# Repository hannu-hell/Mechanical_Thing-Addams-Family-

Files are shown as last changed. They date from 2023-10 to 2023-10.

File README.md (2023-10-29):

# Mechanical_Thing-Addams-Family-
Mechanical Build of the Thing from Addams Family later featured on Netflix series Wednesday.
This project is an open source project powered by Raspberry Pi Pico W. Make sure to use the latest firmware on Pico W for Bluetooth to work.
Please follow on instructables for full build instructions.
There are two micropython files. One for the robot and one for the remote control.

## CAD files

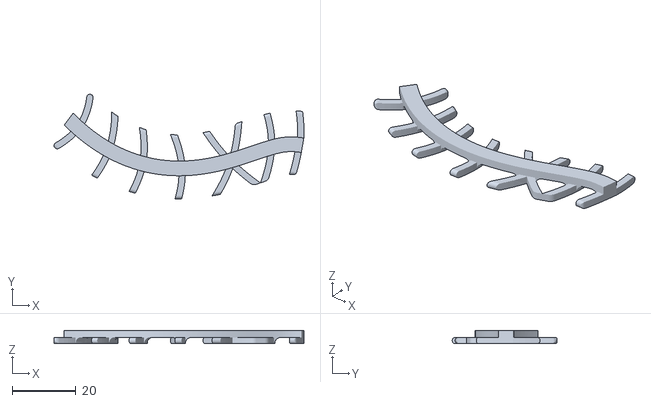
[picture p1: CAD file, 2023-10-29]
Palm_Right_Stitch.stl
78.2 x 32.7 x 4.20

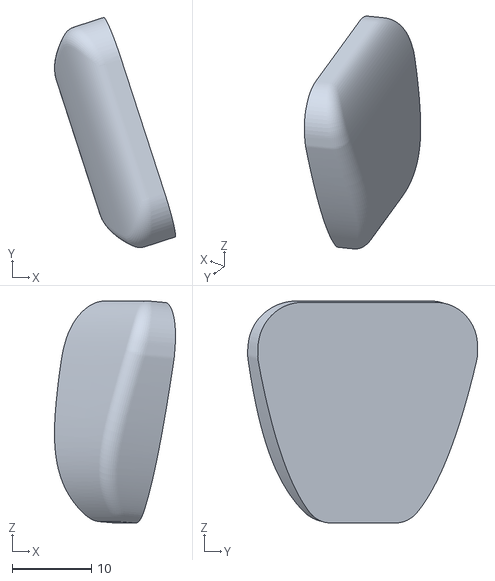
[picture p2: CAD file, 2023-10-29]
Thumb_Finger_Nail.stl
15.3 x 29.1 x 28.1

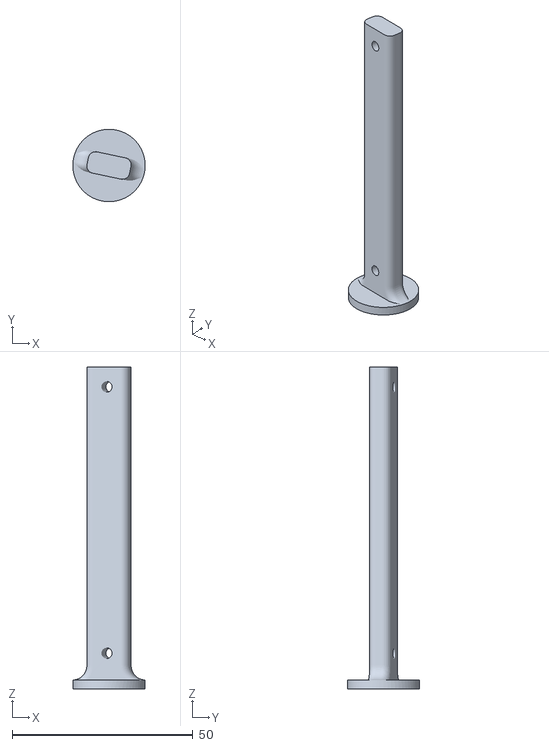
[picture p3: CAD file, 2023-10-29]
Pico_Stand.stl
20.0 x 20.0 x 89.0

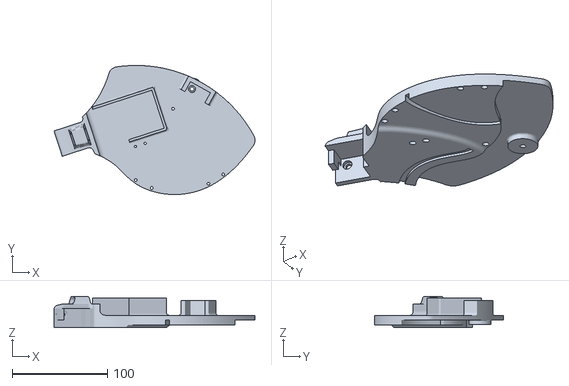
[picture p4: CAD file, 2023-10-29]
Thumb_Base.stl
211.3 x 135.7 x 33.0

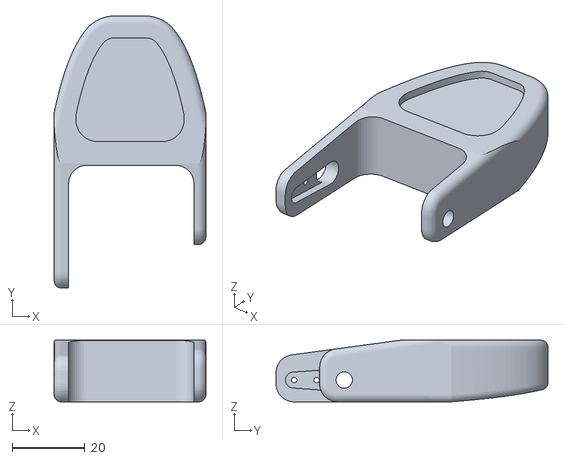
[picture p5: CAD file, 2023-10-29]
Thumb_Finger_Tip.stl
41.8 x 74.9 x 17.0

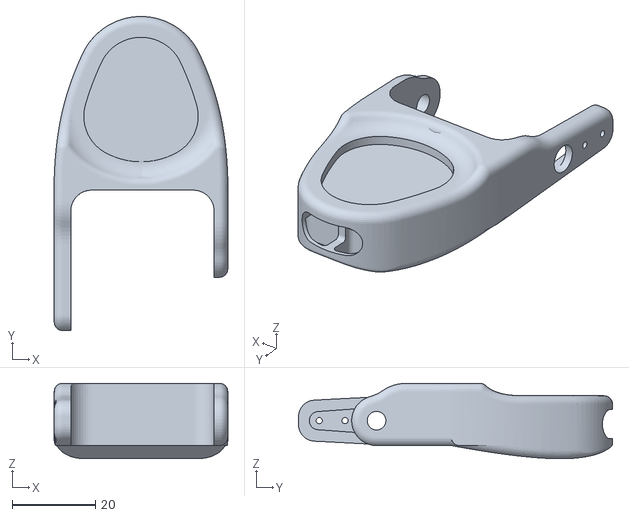
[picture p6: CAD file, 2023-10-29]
Finger_Tip.stl
41.8 x 75.6 x 18.2

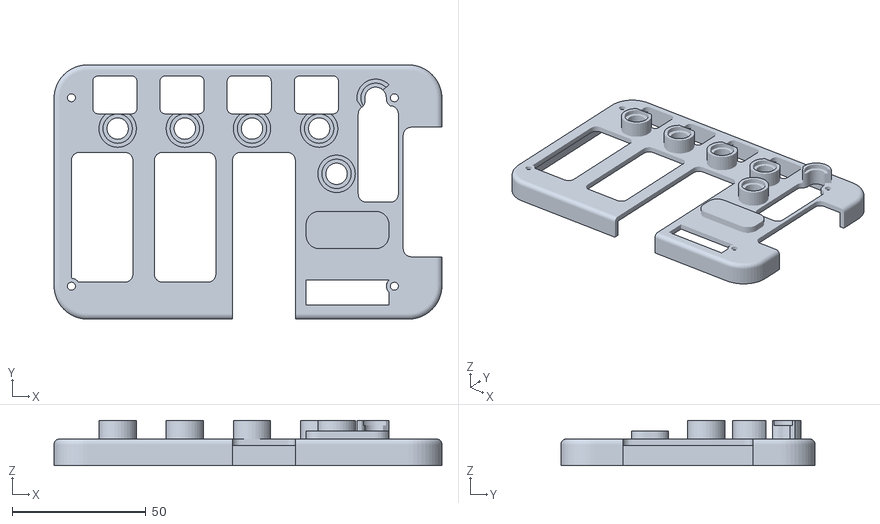
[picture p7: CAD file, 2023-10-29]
Remote_Top_Case.stl
145.0 x 95.0 x 17.0

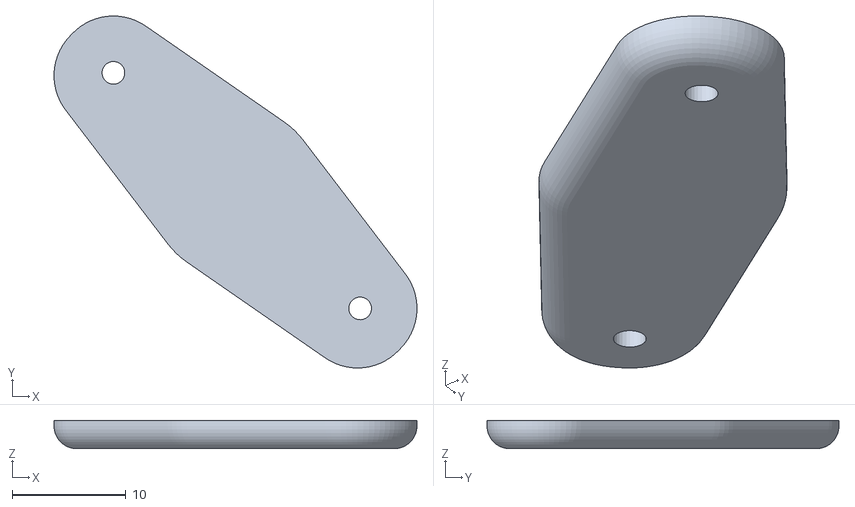
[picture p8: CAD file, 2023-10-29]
Base_Servo_Cap.stl
31.9 x 31.0 x 2.50

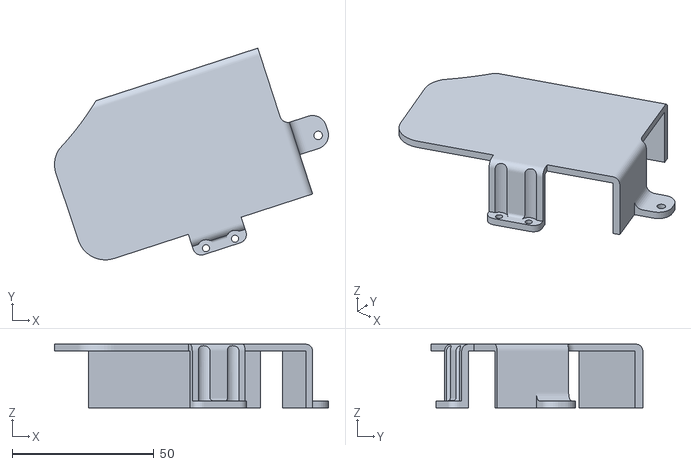
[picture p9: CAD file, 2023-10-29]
Battery_Panel.stl
96.8 x 74.8 x 22.5

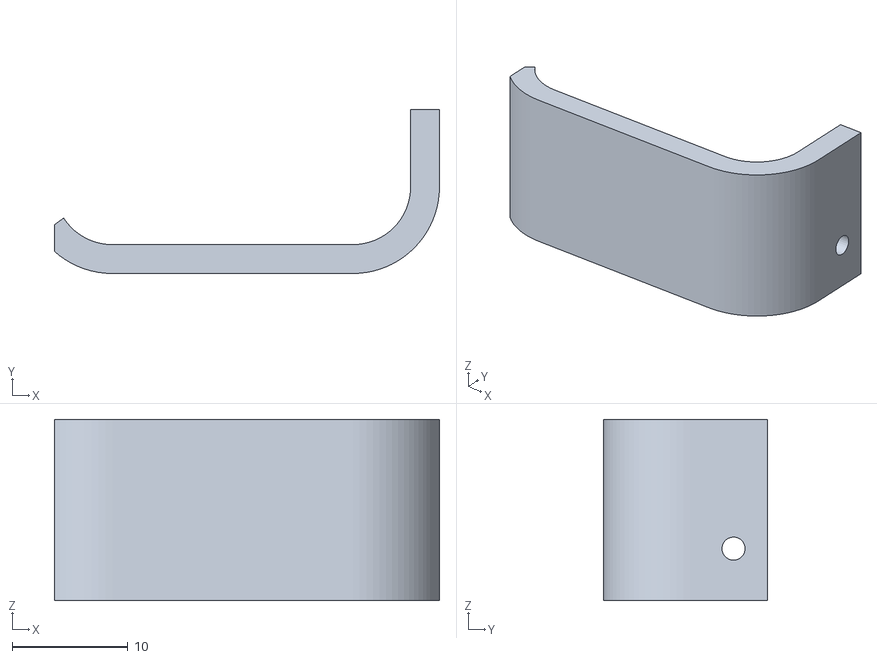
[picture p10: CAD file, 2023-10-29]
Buck_Convertor_Cover.stl
33.3 x 14.2 x 15.7

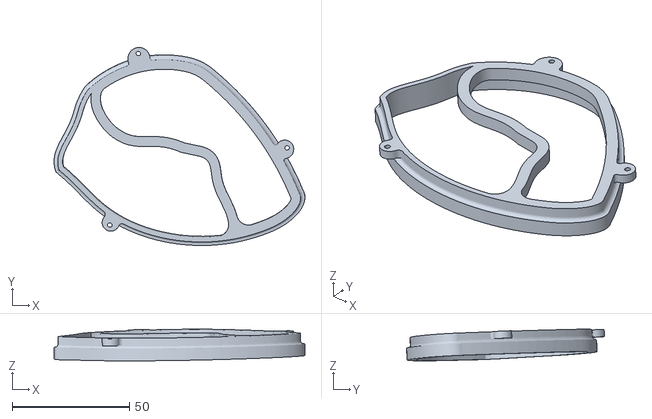
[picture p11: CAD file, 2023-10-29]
Wrist_Top_Cap.stl
106.8 x 84.3 x 13.5

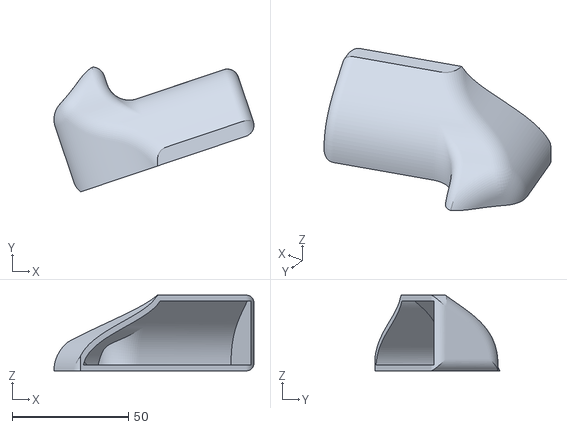
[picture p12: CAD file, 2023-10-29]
Hand_Panel.stl
85.9 x 53.6 x 32.5

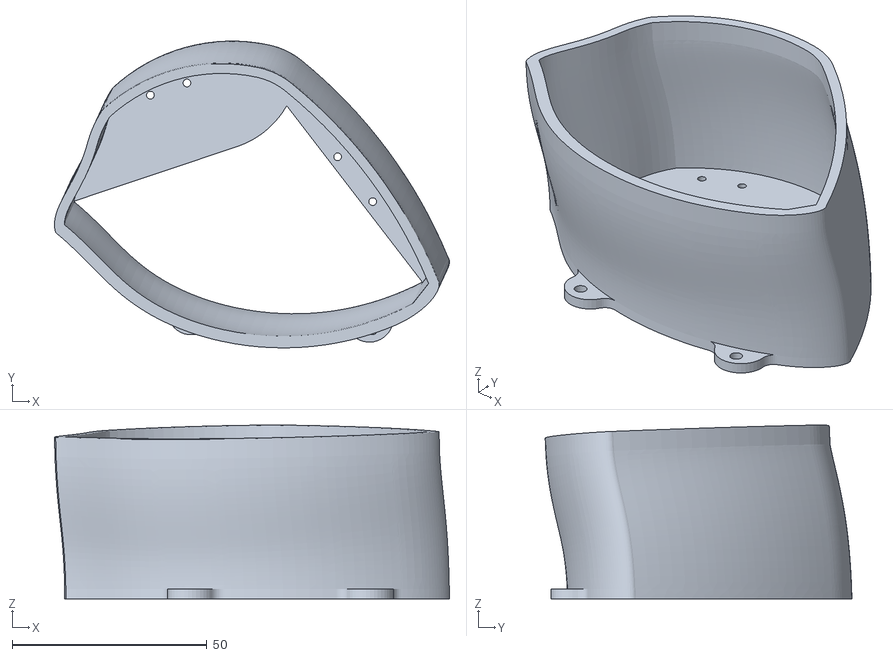
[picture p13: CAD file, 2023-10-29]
Wrist_Top.stl
101.4 x 78.7 x 44.6

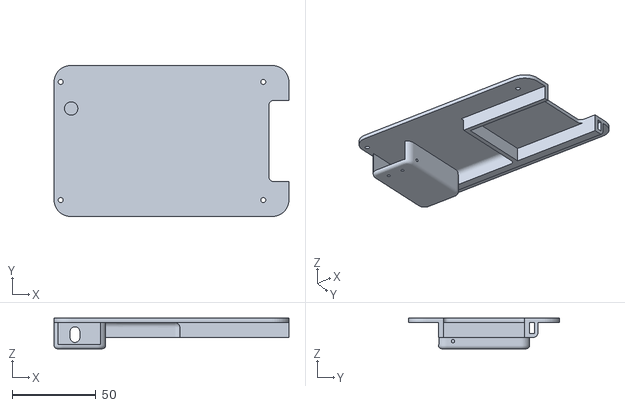
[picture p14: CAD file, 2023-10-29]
Remote_Base.stl
140.0 x 90.0 x 18.2

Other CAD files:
Index_Finger_Mid.stl
Hand_Front.stl
Finger_Nail.stl
Fingers_Horn.stl
Cracked_Finger_Nail.stl
Index_Finger_Base.stl
Wrist.stl

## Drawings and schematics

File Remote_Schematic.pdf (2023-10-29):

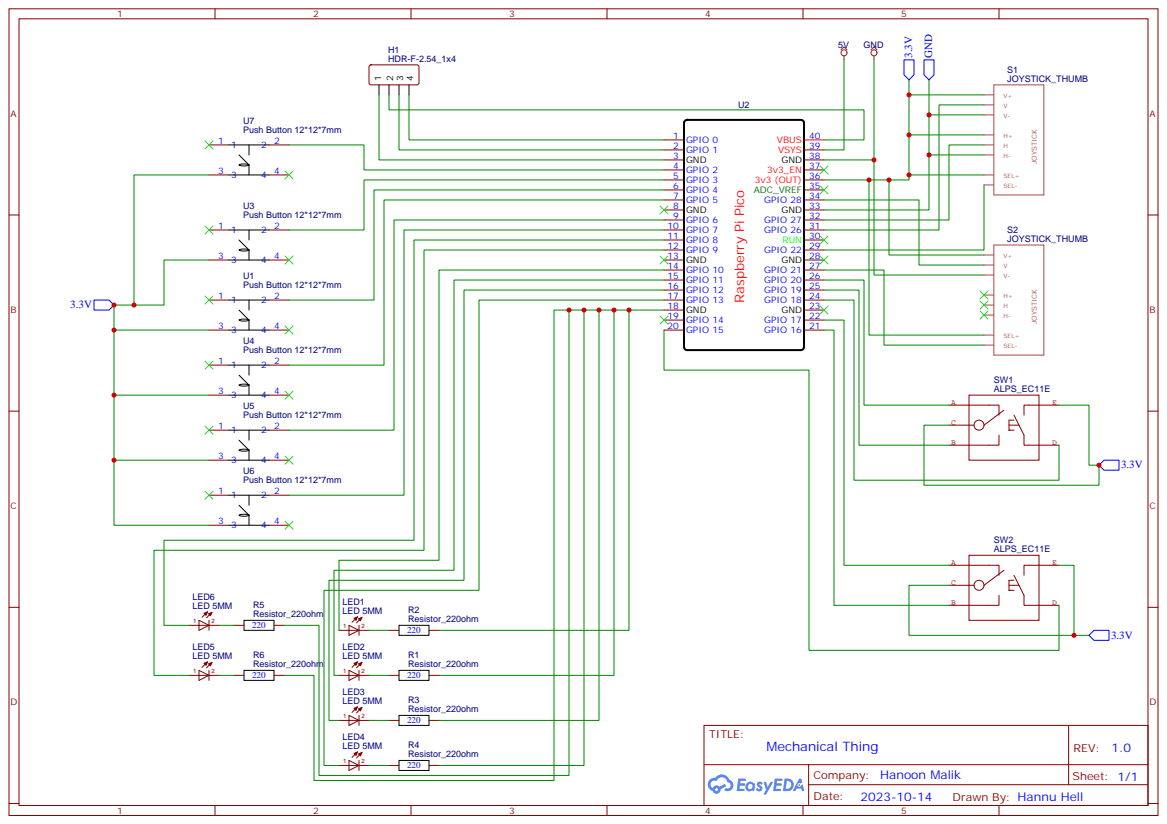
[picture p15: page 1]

Drawn By: Hannu Hell

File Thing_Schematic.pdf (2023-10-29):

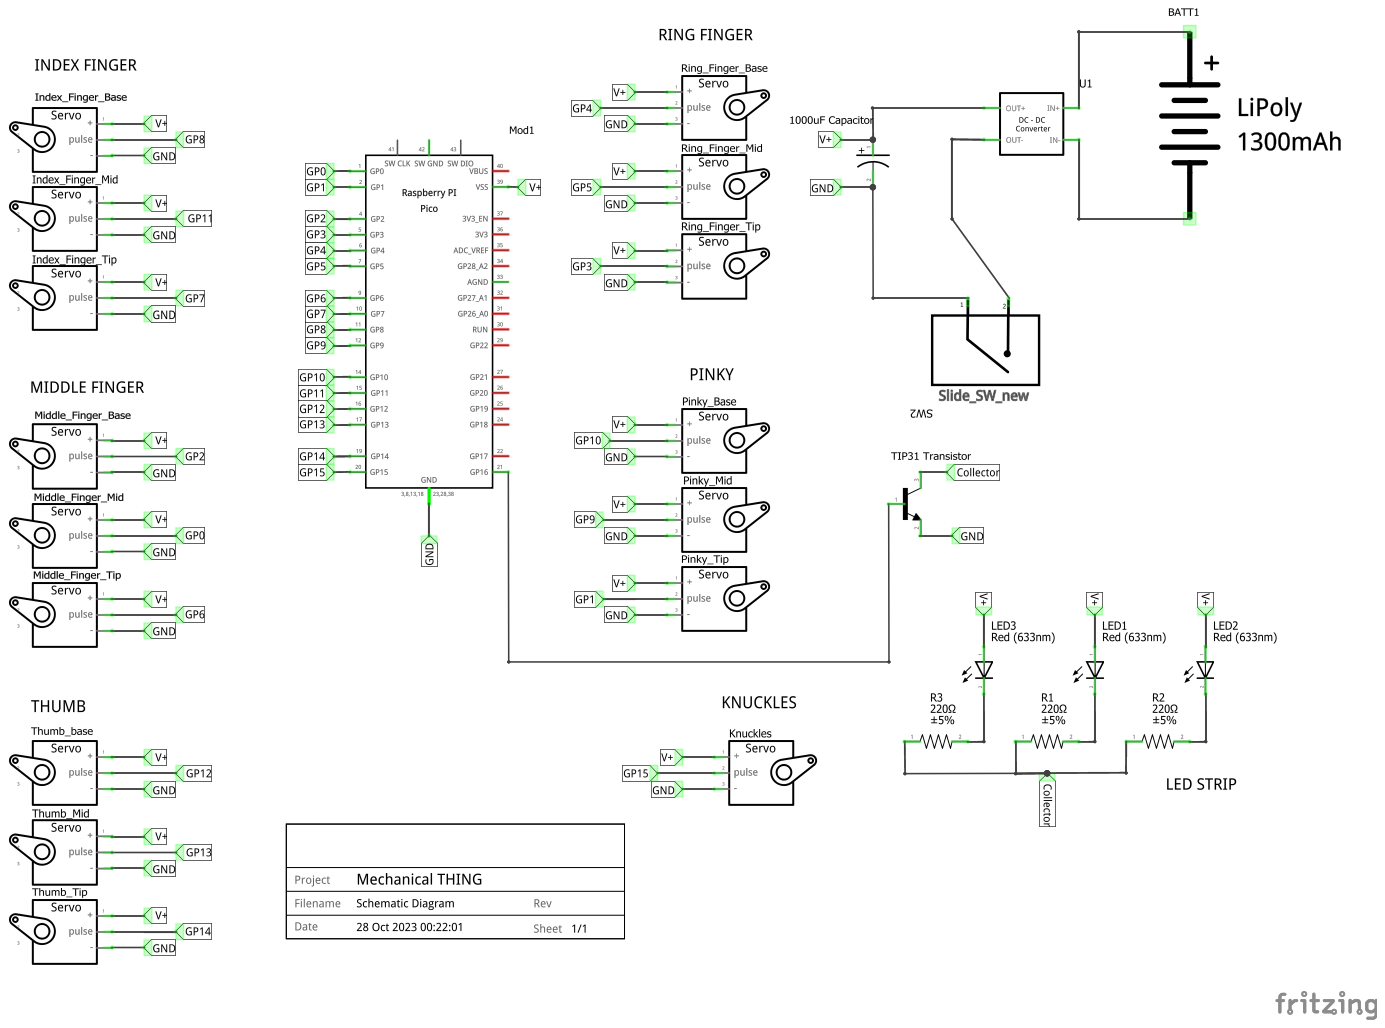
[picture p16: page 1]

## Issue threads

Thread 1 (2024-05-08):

Can you provide the full 3d design file?

pepijndik, 2024-05-08:
First of all what an awesome project!
For school, we are working on exactly the same and thought let's use your instructables as an example ;-) Now we are facing a small issue. We wanted to reuse your design and alter it a bit. But because those are STL files we can't modify them.  en because converting them into a mesh didn't work. so  I thought maybe you could share the cad files instead of the. stl files

Kind regards!

hannu-hell, 2024-05-09:
Hi pepjin,

Glad that you liked my project and its of use to your studies. I’ll figure out a way to embed the design in the instructable so that u will be able to open it in fusion360.

Sorry for the late reply.
Kind regards,
Hannu
Sent from my iPhone

On 08-05-2024, at 21:59, pepijn ***@***.***> wrote:

First of all what an awesome project!
For school, we are working on exactly the same and thought let's use your instructables as an example ;-) Now we are facing a small issue. We wanted to reuse your design and alter it a bit. But because those are STL files we can't modify them. en because converting them into a mesh didn't work. so I thought maybe you could share the cad files instead of the. stl files

Kind regards!

—
Reply to this email directly, view it on GitHub<https://github.com/hannu-hell/Mechanical_Thing-Addams-Family-/issues/1>, or unsubscribe<https://github.com/notifications/unsubscribe-auth/AJKEGCPOTOZHCNZXDDYAFNDZBIVUZAVCNFSM6AAAAABHNBB45WVHI2DSMVQWIX3LMV43ASLTON2WKOZSGI4DKNRXG44TMOA>.
You are receiving this because you are subscribed to this thread.Message ID: ***@***.***>

pepijndik, 2024-05-09:
Thx would be nice, if you only could share them through github also fine😃.

Kind regards

hannu-hell, 2024-05-14:
Hi Pepjin,
I am unable to share the fusion360 file here since its not supported here. Provide me your email and Ill be able to attach the file and send it to you.

Kind Regards

hannu-hell, 2024-05-14:
Oh nevermind,
I've uploaded the file to the repository. Hope it helps.

Closed 2024-06-13.

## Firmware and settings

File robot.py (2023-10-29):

from machine import Pin
import time
from servo import Servo

import aioble
import bluetooth
import machine
import uasyncio as asyncio

# Bluetooth UUIDS can be found online at https://www.bluetooth.com/specifications/gatt/services/
_REMOTE_UUID = bluetooth.UUID(0x1848)
_ENV_SENSE_UUID = bluetooth.UUID(0x1800) 
_REMOTE_CHARACTERISTICS_UUID = bluetooth.UUID(0x2A6E)

# Pico onboard LED for bluetooth connectivity indication
led = machine.Pin("LED", machine.Pin.OUT)
connected = False
alive = False

wrist_led = Pin(16, Pin.OUT)
wrist_led.value(0)

# Finger Servo Pin Definitions
ib = 8
im = 11
it = 7

mb = 2
mm = 0
mt = 6

rb = 4
rm = 5
rt = 3

pb = 10
pm = 9
pt = 1

tb = 12
tm = 13
tt = 14

# Knuckles servo Pin definition
w = 15

# Create servo objects for all the joints
# Index Finger
i_b = Servo(pin_id=ib)
i_m = Servo(pin_id=im)
i_t = Servo(pin_id=it)
# Middle Finger
m_b = Servo(pin_id=mb)
m_m = Servo(pin_id=mm)
m_t = Servo(pin_id=mt)
# Ring FInger
r_b = Servo(pin_id=rb)
r_m = Servo(pin_id=rm)
r_t = Servo(pin_id=rt)
# Pinky 
p_b = Servo(pin_id=pb)
p_m = Servo(pin_id=pm)
p_t = Servo(pin_id=pt)
# Thumb
t_b = Servo(pin_id=tb)
t_m = Servo(pin_id=tm)
t_t = Servo(pin_id=tt)
# Knuckles
wrt = Servo(pin_id=w)

delay_ms = 20


async def find_remote():
    # Scan for 5 seconds, in active mode, with very low interval/window (to
    # maximise detection rate).
    async with aioble.scan(5000, interval_us=30000, window_us=30000, active=True) as scanner:
        async for result in scanner:

            # See if it matches our name
            if result.name() == "TheThing":
                print("Found The_Thing")
                for item in result.services():
                    print (item)
                if _ENV_SENSE_UUID in result.services():
                    print("Found Robot Remote Service")
                    return result.device
            
    return None

async def blink_task():
    """ Blink the LED on and off every second """
    
    toggle = True
    
    while True and alive:
        led.value(toggle)
        toggle = not toggle
        # print(f'blink {toggle}, connected: {connected}')
        if connected:
            blink = 1000
        else:
            blink = 250
        await asyncio.sleep_ms(blink)

async def peripheral_task():
    print('starting peripheral task')
    global connected
    connected = False
    device = await find_remote()
    if not device:
        print("Robot Remote not found")
        return
    try:
        print("Connecting to", device)
        connection = await device.connect()
        
    except asyncio.TimeoutError:
        print("Timeout during connection")
        return
      
    async with connection:
        print("Connected")
        connected = True
        alive = True
        while True and alive:
            try:
                robot_service = await connection.service(_REMOTE_UUID)
                print(robot_service)
                control_characteristic = await robot_service.characteristic(_REMOTE_CHARACTERISTICS_UUID)
                print(control_characteristic)
            except asyncio.TimeoutError:
                print("Timeout discovering services/characteristics")
                return
            while True:
                if control_characteristic != None:
                    try:
                        command = await control_characteristic.read()
                        if command == b'r':
                            print("a button pressed")
                            crouch_pos()
                        if command == b'b':
                            print("b button pressed")
                            get_up()
                        if command == b'g':
                            print("x button pressed")
                            finger_stamp()
                        if command == b'y':
                            print("y button pressed")
                            point_finger()
                        if command == b'w':
                            print("y button pressed")
                            bow_down()
                        if command == b'k':
                            print("y button pressed")
                            rise_up()
                        if command == b'x':
                            print("y button pressed")
                            crouch_walk_forward()
                        if command == b'z':
                            print("y button pressed")
                            crouch_walk_backward()
                        if command == b'v':
                            print("y button pressed")
                            stand_walk()
                    except TypeError:
                        print(f'something went wrong; remote disconnected?')
                        connected = False
                        alive = False
                        return
                    except asyncio.TimeoutError:
                        print(f'something went wrong; timeout error?')
                        connected = False
                        alive = False
                        return
                    except asyncio.GattError:
                        print(f'something went wrong; Gatt error - did the remote die?')
                        connected = False
                        alive = False
                        return
                else:
                    print('no characteristic')
                await asyncio.sleep_ms(10)

async def main():
    tasks = []
    tasks = [
        asyncio.create_task(blink_task()),
        asyncio.create_task(peripheral_task()),
    ]
    await asyncio.gather(*tasks)

def wrist_led_seq():
    wrist_led.value(0)
    time.sleep(2)
    wrist_led.value(0)
    for i in range (3):
        wrist_led.value(1)
        time.sleep(0.1)
        wrist_led.value(0)
        time.sleep(0.1)
    wrist_led.value(1)

def straight_fingers():
    i_b.write(76)
    i_m.write(15)
    i_t.write(55)

    m_b.write(87)
    m_m.write(44)
    m_t.write(58)

    r_b.write(85)
    r_m.write(35)
    r_t.write(60)

    p_b.write(88)
    p_m.write(45)
    p_t.write(45)
    
    t_b.write(88)
    t_m.write(48)
    t_t.write(78)
    
    time.sleep(1)
   
def rise_up():
    straight_fingers()
    time.sleep(2)

    t_b.write(84)
    t_m.write(80)
    t_t.write(170)
    time.sleep(2)

    t_b.write(84-50)
    t_m.write(48+100)
    time.sleep(1)
    t_b.write(88-50)
    t_m.write(48+70)
    t_t.write(78+52)
    time.sleep(1)

    t_b.write(88-60)
    t_m.write(48+90)
    t_t.write(78+52)

    time.sleep(0.5)

    i_b.write(76-20)
    i_m.write(15)
    i_t.write(55)
    time.sleep(1)
    m_b.write(87-20)
    m_m.write(44)
    m_t.write(58)

    r_b.write(85-20)
    r_m.write(35)
    r_t.write(60)

    p_b.write(88-20)
    p_m.write(45)
    p_t.write(45)

    time.sleep(1)

    t_b.write(88-4)
    t_m.write(48+125)
    t_t.write(78-32)
    time.sleep(1)
    p_b.write(88-27)
    p_m.write(45+30)
    p_t.write(45+87)
    time.sleep(1)
    i_b.write(76-27)
    i_m.write(15+30)
    i_t.write(55+87)

    m_b.write(87-27)
    m_m.write(44+30)
    m_t.write(58+87)

    r_b.write(85-27)
    r_m.write(35+30)
    r_t.write(60+87)

    time.sleep(1)
    p_b.write(88-12)
    p_m.write(45+104)
    p_t.write(45-2)

    t_b.write(88-4)
    t_m.write(48+125)
    t_t.write(78-32)

    time.sleep(1)
    r_b.write(85-12)
    r_m.write(35+104)
    r_t.write(60-2)
    time.sleep(1)
    m_b.write(87-12)
    m_m.write(44+104)
    m_t.write(58-2)
    time.sleep(1)
    i_b.write(76-12)
    i_m.write(15+104)
    i_t.write(55-2)

    time.sleep(1)

    crouch_pos()
    time.sleep(1)
    crouch_walk_backward(steps=1)

    time.sleep(1)
    t_b.write(88-6)
    t_m.write(48+145)
    t_t.write(78-10)
    time.sleep(1)
    get_up()

def finger_stamp():
    for i in range(10):
        i_b.write(76-4)
        i_m.write(15+125)
        i_t.write(55-32)
        time.sleep(0.1)
        i_b.write(76-63)
        i_m.write(15+138)
        i_t.write(55+15)
        time.sleep(0.1)
        i_b.write(76-12)
        i_m.write(15+104)
        i_t.write(55-2)

        m_b.write(87-4)
        m_m.write(44+125)
        m_t.write(58-32)
        time.sleep(0.1)
        m_b.write(87-63)
        m_m.write(44+138)
        m_t.write(58+15)
        time.sleep(0.1)
        m_b.write(87-12)
        m_m.write(44+104)
        m_t.write(58-2)

        r_b.write(85-4)
        r_m.write(35+125)
        r_t.write(60-32)

        p_b.write(88-4)
        p_m.write(45+125)
        p_t.write(45-32)

        t_b.write(88-4)
        t_m.write(48+125)
        t_t.write(78-32)

def get_up():
    i_b.write(76-4)
    i_m.write(15+125)
    i_t.write(55-32)
    
    m_b.write(87-4)
    m_m.write(44+125)
    m_t.write(58-32)

    r_b.write(85-4)
    r_m.write(35+125)
    r_t.write(60-32)

    p_b.write(88-4)
    p_m.write(45+125)
    p_t.write(45-32)

    t_b.write(88-4)
    t_m.write(48+125)
    t_t.write(78-32)
    
    time.sleep(2)
    
    m_b.write(87+59)
    m_m.write(44+60)
    m_t.write(58-29)

    r_b.write(85+59)
    r_m.write(35+60)
    r_t.write(60-29)

    p_b.write(88+59)
    p_m.write(45+60)
    p_t.write(45-29)
    
    t_b.write(88+59)
    t_m.write(48+60)
    t_t.write(78-29)
        
    i_b.write(76+59)
    i_m.write(15+60)
    i_t.write(55-29)
    
def point_finger(point_count=4):
    m_b.write(87+59)
    m_m.write(44+60)
    m_t.write(58-29)

    r_b.write(85+59)
    r_m.write(35+60)
    r_t.write(60-29)

    p_b.write(88+59)
    p_m.write(45+60)
    p_t.write(45-29)

    t_b.write(88+59)
    t_m.write(48+60)
    t_t.write(78-29)
        
    i_b.write(76+59)
    i_m.write(15+60)
    i_t.write(55-29)
    # time.sleep(2)
    for i in range(point_count):
        i_b.write(76-59)
        i_m.write(15+119)
        i_t.write(55+20)
        time.sleep(0.2)
        i_b.write(76+10)
        i_m.write(15)
        i_t.write(55+20)
        time.sleep(0.3)
    time.sleep(1)
    i_b.write(76+59)
    i_m.write(15+60)
    i_t.write(55-29)
    
def struggle():
    i_b.write(76-28)
    i_m.write(15+47)
    i_t.write(55+37)

    m_b.write(87-28)
    m_m.write(44+47)
    m_t.write(58+37)

    r_b.write(85-28)
    r_m.write(35+47)
    r_t.write(60+37)

    p_b.write(88-28)
    p_m.write(45+47)
    p_t.write(45+37)

    t_b.write(88-28)
    t_m.write(48+47)
    t_t.write(78+37)

    for i in range(48, 140):
        i_b.write(i)
        m_b.write(i)
        r_b.write(i)
        p_b.write(i)
        t_b.write(i)
        time.sleep(0.01)
    for i in reversed(range(48, 140)):
        i_b.write(i)
        m_b.write(i)
        r_b.write(i)
        p_b.write(i)
        t_b.write(i)
        time.sleep(0.01)
    
def bow_down(bowTime=2):
    get_up()
    time.sleep(2)
    wrt.write(90)
    time.sleep(0.5)
    
    for i in range(26,155):
        i_t.write(i)
        time.sleep(0.01)
    for i in reversed(range(35,75)):
        i_m.write(i)
        time.sleep(0.02)
    
    for i in range(29,158):
        m_t.write(i)
        time.sleep(0.01)
    for i in reversed(range(64,104)):
        m_m.write(i)
        time.sleep(0.02)
 
    time.sleep(1)

    for i in range(144,175):
        r_b.write(i)
        time.sleep(0.02)
    for i in range(95,105):
        r_m.write(i)
        time.sleep(0.02)
    for i in range(31,90):
        r_t.write(60+30)
        time.sleep(0.02)
    
    time.sleep(bowTime)
    get_up()
    
def tap_fingers(tapCount=8,tapSpeed=0.05):
    for i in range(tapCount):
        t = tapSpeed
        i_t.write(55+80)
        i_m.write(15+37)
        i_b.write(76-47)

        time.sleep(t)

        m_t.write(58+80)
        m_m.write(44+37)
        m_b.write(87-47)

        time.sleep(t)

        r_t.write(60+80)
        r_m.write(35+37)
        r_b.write(85-47)

        time.sleep(t)

        p_t.write(45+80)
        p_m.write(45+37)
        p_b.write(88-47)

        time.sleep(t)

        i_b.write(76-25)
        i_m.write(15+25)
        i_t.write(55+70)

        time.sleep(t)

        m_b.write(87-25)
        m_m.write(44+25)
        m_t.write(58+70)

        time.sleep(t)

        r_b.write(85-25)
        r_m.write(35+25)
        r_t.write(60+70)

        time.sleep(t)

        p_b.write(88-25)
        p_m.write(45+25)
        p_t.write(45+70)
              
def trick_or_treat():
    for i in range(2):
        i_b.write(76+10)
        i_m.write(15+20)
        i_t.write(55+20)

        m_b.write(87+10)
        m_m.write(44+40)
        m_t.write(58+20)

        r_b.write(85+10)
        r_m.write(35+50)
        r_t.write(60+20)

        p_b.write(88+10)
        p_m.write(45+70)
        p_t.write(45+20)

        t_b.write(88+10)
        t_m.write(48+20)
        t_t.write(78+20)

        time.sleep(2)

        i_b.write(76+80)
        i_m.write(15+30)
        i_t.write(55+65)

        m_b.write(87+80)
        m_m.write(44+30)
        m_t.write(58+60)

        r_b.write(85+80)
        r_m.write(35+35)
        r_t.write(60+60)

        p_b.write(88+90)
        p_m.write(45+35)
        p_t.write(45+60)

        t_b.write(88+60)
        t_m.write(48+40)
        t_t.write(78+80)
        
        time.sleep(2)

    i_b.write(76+10)
    i_m.write(15+20)
    i_t.write(55+20)

    for i in range(3):
        for i in reversed(range(35, 55)):
            i_m.write(i)
            time.sleep(0.003)
        for i in reversed(range(75, 120)):
            i_t.write(i)
            time.sleep(0.003)

        time.sleep(0.1)
        for i in range(75, 120):
             i_t.write(i)
             time.sleep(0.003)
        for i in range(35, 55):
            i_m.write(i)
            time.sleep(0.003)

def _initial():  # Private function used in the finger_count function
    i_b.write(76+60)
    i_m.write(15+70)
    i_t.write(55+80)

    m_b.write(87+60)
    m_m.write(44+70)
    m_t.write(58+80)

    r_b.write(85+60)
    r_m.write(35+70)
    r_t.write(60+80)

    p_b.write(88+60)
    p_m.write(45+70)
    p_t.write(45+75)

    t_b.write(88+60)
    t_m.write(48+70)
    t_t.write(78+80)


def finger_count():
    _initial()
    time.sleep(1)

    i_b.write(76+60)
    i_m.write(15+30)
    i_t.write(55+10)

    time.sleep(1)
    for i in range(3):    
        wrt.write(80)
        time.sleep(0.1)
        wrt.write(100)
        time.sleep(0.1)
    wrt.write(90)

    time.sleep(1)

    _initial()
    time.sleep(1)

    i_b.write(76+60)
    i_m.write(15+30)
    i_t.write(55+10)

    m_b.write(87+60)
    m_m.write(44+30)
    m_t.write(58+10)

    time.sleep(1)

    for i in range(3):    
        wrt.write(80)
        time.sleep(0.1)
        wrt.write(100)
        time.sleep(0.1)
    wrt.write(90)
    time.sleep(1)

    _initial()
    time.sleep(1)

    i_b.write(76+60)
    i_m.write(15+30)
    i_t.write(55+10)

    m_b.write(87+60)
    m_m.write(44+30)
    m_t.write(58+10)

    r_b.write(85+60)
    r_m.write(35+30)
    r_t.write(60+10)

    time.sleep(1)
    for i in range(3):    
        wrt.write(80)
        time.sleep(0.1)
        wrt.write(100)
        time.sleep(0.1)
    wrt.write(90)
    time.sleep(1)
    _initial()
    time.sleep(1)
    i_b.write(76+60)
    i_m.write(15+30)
    i_t.write(55+10)

    m_b.write(87+60)
    m_m.write(44+30)
    m_t.write(58+10)

    r_b.write(85+60)
    r_m.write(35+30)
    r_t.write(60+10)

    p_b.write(88+60)
    p_m.write(45+30)
    p_t.write(45+10)

    time.sleep(1)

    for i in range(3):    
        wrt.write(80)
        time.sleep(0.1)
        wrt.write(100)
        time.sleep(0.1)
    wrt.write(90)
    time.sleep(1)

    _initial()

    t_b.write(88+60)
    t_m.write(48+70)
    t_t.write(78+80)


def crouch_walk_forward(steps=3, step_speed=0.1, speed=0.3):
    for i in range(steps):
        i_b.write(76-4)
        i_m.write(15+125)
        i_t.write(55-32)

        m_b.write(87-4)
        m_m.write(44+125)
        m_t.write(58-32)
        
        r_b.write(85-4)
        r_m.write(35+125)
        r_t.write(60-32)
        
        p_b.write(88-4)
        p_m.write(45+125)
        p_t.write(45-32)
        
        t_b.write(88-12)
        t_m.write(48+104)
        t_t.write(78-2)
        
        time.sleep(speed)

        i_b.write(76-63)
        i_m.write(15+138)
        i_t.write(55+15)
        time.sleep(step_speed)
        i_b.write(76-12)
        i_m.write(15+104)
        i_t.write(55-2)

        time.sleep(speed)
        
        m_b.write(87-63)
        m_m.write(44+138)
        m_t.write(58+15)
        time.sleep(step_speed)
        m_b.write(87-12)
        m_m.write(44+104)
        m_t.write(58-2)
        
        time.sleep(speed)
        
        r_b.write(85-63)
        r_m.write(35+138)
        r_t.write(60+15)
        time.sleep(step_speed)
        r_b.write(85-12)
        r_m.write(35+104)
        r_t.write(60-2)
        
        time.sleep(speed)
        
        p_b.write(88-63)
        p_m.write(45+138)
        p_t.write(45+15)
        p_b.write(88-12)
        p_m.write(45+104)
        p_t.write(45-2)
        
        time.sleep(speed)
        
        t_b.write(88-63)
        t_m.write(48+138)
        t_t.write(78+15)
        t_b.write(88-4)
        t_m.write(48+125)
        t_t.write(78-32)

        time.sleep(speed)

        i_b.write(76-4)
        i_m.write(15+125)
        i_t.write(55-32)

        m_b.write(87-4)
        m_m.write(44+125)
        m_t.write(58-32)
        
        r_b.write(85-4)
        r_m.write(35+125)
        r_t.write(60-32)

        p_b.write(88-4)
        p_m.write(45+125)
        p_t.write(45-32)

        t_b.write(88-12)
        t_m.write(48+104)
        t_t.write(78-2)

def crouch_walk_backward(steps=3, step_speed=0.1, speed=0.3):
    for i in range(steps):
        i_b.write(76-12)
        i_m.write(15+104)
        i_t.write(55-2)

        m_b.write(87-12)
        m_m.write(44+104)
        m_t.write(58-2)
        
        r_b.write(85-12)
        r_m.write(35+104)
        r_t.write(60-2)
        
        p_b.write(88-12)
        p_m.write(45+104)
        p_t.write(45-2)
        
        t_b.write(88-4)
        t_m.write(48+125)
        t_t.write(78-32)
        
        time.sleep(speed)

        i_b.write(76-63)
        i_m.write(15+138)
        i_t.write(55+15)
        time.sleep(step_speed)
        i_b.write(76-4)
        i_m.write(15+125)
        i_t.write(55-32)

        time.sleep(speed)
        
        m_b.write(87-63)
        m_m.write(44+138)
        m_t.write(58+15)
        time.sleep(step_speed)
        m_b.write(87-4)
        m_m.write(44+125)
        m_t.write(58-32)
        
        time.sleep(speed)
        
        r_b.write(85-63)
        r_m.write(35+138)
        r_t.write(60+15)
        time.sleep(step_speed)
        r_b.write(85-4)
        r_m.write(35+125)
        r_t.write(60-32)
        
        time.sleep(speed)
        
        p_b.write(88-63)
        p_m.write(45+138)
        p_t.write(45+15)
        p_b.write(88-4)
        p_m.write(45+125)
        p_t.write(45-32)
        
        time.sleep(speed)
        
        t_b.write(88-63)
        t_m.write(48+138)
        t_t.write(78+15)
        t_b.write(88-12)
        t_m.write(48+104)
        t_t.write(78-2)

        time.sleep(speed)

        i_b.write(76-12)
        i_m.write(15+104)
        i_t.write(55-2)

        m_b.write(87-12)
        m_m.write(44+104)
        m_t.write(58-2)
        
        r_b.write(85-12)
        r_m.write(35+104)
        r_t.write(60-2)

        p_b.write(88-12)
        p_m.write(45+104)
        p_t.write(45-2)

        t_b.write(88-4)
        t_m.write(48+125)
        t_t.write(78-32)

def crouch_pos():
    i_b.write(76-12)
    i_m.write(15+104)
    i_t.write(55-2)

    m_b.write(87-12)
    m_m.write(44+104)
    m_t.write(58-2)

    r_b.write(85-12)
    r_m.write(35+104)
    r_t.write(60-2)

    p_b.write(88-12)
    p_m.write(45+104)
    p_t.write(45-2)

    t_b.write(88-4)
    t_m.write(48+125)
    t_t.write(78-32)
    
def stand_walk():
    get_up()
    for i in range(3):
        wrt.write(90)
        time.sleep(0.5)
        m_b.write(87+59)
        m_m.write(44+60)
        m_t.write(58-29)

        r_b.write(85+59)
        r_m.write(35+60)
        r_t.write(60-29)

        p_b.write(88+59)
        p_m.write(45+60)
        p_t.write(45-29)

        t_b.write(88+44)
        t_m.write(48+83)
        t_t.write(78-37)
        
        t = 0.05
        t2 = 0.05

        i_b.write(76+38)
        i_m.write(15+102)
        i_t.write(55-50)
        time.sleep(t)
        i_b.write(76-2)
        i_m.write(15+124)
        i_t.write(55-22)
        time.sleep(t)
        i_t.write(55+1)
        time.sleep(t)
        i_m.write(15+76)
        time.sleep(t)
        i_b.write(76+15)

        time.sleep(t2)

        m_b.write(87+34)
        m_m.write(44+111)
        m_t.write(58-54)
        time.sleep(t)
        m_b.write(87-2)
        m_m.write(44+124)
        m_t.write(58-22)
        time.sleep(t)
        m_t.write(58-3)
        time.sleep(t)
        m_m.write(44+84)
        time.sleep(t)
        m_b.write(87+8)



        time.sleep(t2)

        r_b.write(85+38)
        r_m.write(35+102)
        r_t.write(60-50)
        time.sleep(t)
        r_b.write(85-2)
        r_m.write(35+124)
        r_t.write(60-22)
        time.sleep(t)
        r_t.write(60+1)
        time.sleep(t)
        r_m.write(35+76)
        time.sleep(t)
        r_b.write(85+15)

        time.sleep(t2)

        p_b.write(88+79)
        p_m.write(45+20)
        p_t.write(45-10)
        p_b.write(88+9)
        p_m.write(45+112)
        p_t.write(45-31)
        time.sleep(0.02)
        p_t.write(35)
        time.sleep(0.01)
        p_m.write(45+42)
        time.sleep(0.01)
        p_b.write(88+39)
        
        i_b.write(76+38)
        i_m.write(15+102)
        i_t.write(55-50)
        m_b.write(87+34)
        m_m.write(44+111)
        m_t.write(58-54)
        r_b.write(85+38)
        r_m.write(35+102)
        r_t.write(60-50)
        p_b.write(88+17)
        p_m.write(45+105)
        p_t.write(45-50)

    
while True:
    asyncio.run(main())

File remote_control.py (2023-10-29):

#Shoutout to Kevin McAleer for the great intro to using Bluetooth on Raspberry Pi Pico W to build remote control devices for robots.

import sys
import aioble
import bluetooth
import machine
from machine import Pin
from machine import I2C
from machine import ADC
import uasyncio as asyncio
from micropython import const
import time

import ssd1306
import framebuf

i2c = I2C(0, sda=Pin(0), scl=Pin(1))
display = ssd1306.SSD1306_I2C(128, 64, i2c)


def clear_display():
    display.fill(0)
    display.show()
    
# ---------- Display image of Thing on display -----------

display.text('The THING', 28, 0)


with open('hand.pbm', 'rb') as f:
    f.readline() 
    f.readline() 
    f.readline() 
    data = bytearray(f.read())
fbuf = framebuf.FrameBuffer(data, 60, 61, framebuf.MONO_HLSB)
display.blit(fbuf, 35, 12, 0)

display.show()
time.sleep(2)
display.fill(0)
display.text("INITIALIZING", 15, 30)
display.show()
time.sleep(1)
display.text("CAPACITOR CHARGE",0, 40)
display.show()
time.sleep(1)
display.text("READY!", 40, 50)
display.show()
time.sleep(2)
clear_display()

# --------------------------------------------------------

# The Thing - Remote Buttons Pin Assignment
white_button = Pin(2, Pin.IN, Pin.PULL_DOWN)
black_button = Pin(3, Pin.IN, Pin.PULL_DOWN)
green_button = Pin(4, Pin.IN, Pin.PULL_DOWN)
red_button = Pin(5, Pin.IN, Pin.PULL_DOWN)
blue_button = Pin(6, Pin.IN, Pin.PULL_DOWN)
yellow_button = Pin(7, Pin.IN, Pin.PULL_DOWN)


white_led = Pin(8, machine.Pin.OUT)
black_led = Pin(10, machine.Pin.OUT)
green_led = Pin(11, machine.Pin.OUT)
red_led = Pin(12, machine.Pin.OUT)
blue_led = Pin(13, machine.Pin.OUT)
yellow_led = Pin(9, machine.Pin.OUT)

def turn_off_leds():
    white_led.value(0)
    black_led.value(0)
    green_led.value(0)
    red_led.value(0)
    blue_led.value(0)
    yellow_led.value(0)

# Thumb Stick Pin Definitions
adcpin1 = 26
adcpin2 = 27
adcpin3 = 28

# Thumb Stick Pin Assignment
left_thumb1 = ADC(adcpin1)
left_thumb2 = ADC(adcpin2)
right_thumb1 = ADC(adcpin3)

def uid():
    """ Return the unique id of the device as a string """
    return "{:02x}{:02x}{:02x}{:02x}{:02x}{:02x}{:02x}{:02x}".format(
        *machine.unique_id())

MANUFACTURER_ID = const(0x02A29)
MODEL_NUMBER_ID = const(0x2A24)
SERIAL_NUMBER_ID = const(0x2A25)
HARDWARE_REVISION_ID = const(0x2A26)
BLE_VERSION_ID = const(0x2A28)

led = machine.Pin("LED", machine.Pin.OUT)

_ENV_SENSE_UUID = bluetooth.UUID(0x180A)
_GENERIC = bluetooth.UUID(0x1848)
_ENV_SENSE_TEMP_UUID = bluetooth.UUID(0x1800)
_BUTTON_UUID = bluetooth.UUID(0x2A6E)

_BLE_APPEARANCE_GENERIC_REMOTE_CONTROL = const(384)

# Advertising frequency
ADV_INTERVAL_MS = 250_000

device_info = aioble.Service(_ENV_SENSE_UUID)

connection = None

# Create characteristics for device info
aioble.Characteristic(device_info, bluetooth.UUID(MANUFACTURER_ID), read=True, initial="TheThingRemote")
aioble.Characteristic(device_info, bluetooth.UUID(MODEL_NUMBER_ID), read=True, initial="1.0")
aioble.Characteristic(device_info, bluetooth.UUID(SERIAL_NUMBER_ID), read=True, initial=uid())
aioble.Characteristic(device_info, bluetooth.UUID(HARDWARE_REVISION_ID), read=True, initial=sys.version)
aioble.Characteristic(device_info, bluetooth.UUID(BLE_VERSION_ID), read=True, initial="1.0")

remote_service = aioble.Service(_GENERIC)

button_characteristic = aioble.Characteristic(
    remote_service, _BUTTON_UUID, read=True, notify=True
)

print('registering services')
aioble.register_services(remote_service, device_info)

connected = False

async def remote_task():
    """ Send the event to the connected device """
    while True:
        left_thumb1_value = left_thumb1.read_u16()
        right_thumb1_value = right_thumb1.read_u16()
        if not connected:
            print('not connected')
            await asyncio.sleep_ms(1000)
            continue
        if green_button.value():
            button_characteristic.write(b"g")   
            button_characteristic.notify(connection,b"g")
            turn_off_leds()
            green_led.value(1)
            clear_display()
            display.text("FINGER STAMP", 20, 40)
            display.show()
        if red_button.value():
            button_characteristic.write(b"r")   
            button_characteristic.notify(connection,b"r")
            turn_off_leds()
            red_led.value(1)
            clear_display()
            display.text("CROUCH POS", 20, 40)
            display.show()
        if blue_button.value():
            button_characteristic.write(b"b")   
            button_characteristic.notify(connection,b"b")
            turn_off_leds()
            blue_led.value(1)
            clear_display()
            display.text("STAND POS", 20, 40)
            display.show()
        if yellow_button.value():
            button_characteristic.write(b"y")   
            button_characteristic.notify(connection,b"y")
            turn_off_leds()
            yellow_led.value(1)
            clear_display()
            display.text("POINT FINGER", 20, 40)
            display.show()
        if white_button.value():
            button_characteristic.write(b"w")   
            button_characteristic.notify(connection,b"w")
            turn_off_leds()
            white_led.value(1)
            clear_display()
            display.text("LED ON", 20, 40)
            display.show()
        if black_button.value():
            button_characteristic.write(b"k")   
            button_characteristic.notify(connection,b"k")
            turn_off_leds()
            black_led.value(1)
            clear_display()
            display.text("BOW DOWN", 20, 40)
            display.show()
        if left_thumb1_value > 40000:
            button_characteristic.write(b"x")   
            button_characteristic.notify(connection,b"x")
            clear_display()
            display.text("CROUCH FWD", 20, 40)
            display.show()
        if left_thumb1_value < 20000:
            button_characteristic.write(b"z")   
            button_characteristic.notify(connection,b"z")
            clear_display()
            display.text("CROUCH BWD", 20, 40)
            display.show()
        if right_thumb1_value > 40000:
            button_characteristic.write(b"v")   
            button_characteristic.notify(connection,b"v")
            clear_display()
            display.text("STAND WALK", 20, 40)
            display.show()
        else:
            button_characteristic.write(b"!")
        await asyncio.sleep_ms(10)
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

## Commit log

2023-10-29 PCB Gerber file for ssd1306 oled I had
2023-10-29 Gerber for PCB with typical OLED pins
2023-10-29 3D Model Files
    [Base_Servo_Cap.stl, Battery_Panel.stl, Buck_Convertor_Cover.stl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]
2023-10-29 Schematic Diagram of the Robot
2023-10-29 Schematic diagram of Remote Control
2023-10-30 Hand pbm file
    Upload to raspberry Pi Pico drive to use on ssd1306
